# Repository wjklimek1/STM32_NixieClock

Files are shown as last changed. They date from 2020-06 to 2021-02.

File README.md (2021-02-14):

# STM32_NixieClock
Nixie clock based on STM32F103C8T6, DS3231 and MC34063

Nixie clock is driven by STM32F103C8T6 MCU reading data from DS3231 RTC clock. Step-up converter controlled by MC34063 produces 170V DC needed to power up display. Lamps are old japanese CD61 niexie tubes. 

Schematics and PCBs were designed with KiCad. In PDF folder you can find schematics from KiCad exported to PDF format for quick preview.

 Microcontroller program was written in C with HAL libraries and FreeRTOS. I know that any operating system is a total overkill when it comes to such a simple project but I used it to get familiar with FreeRTOS before I start more advanced projects.

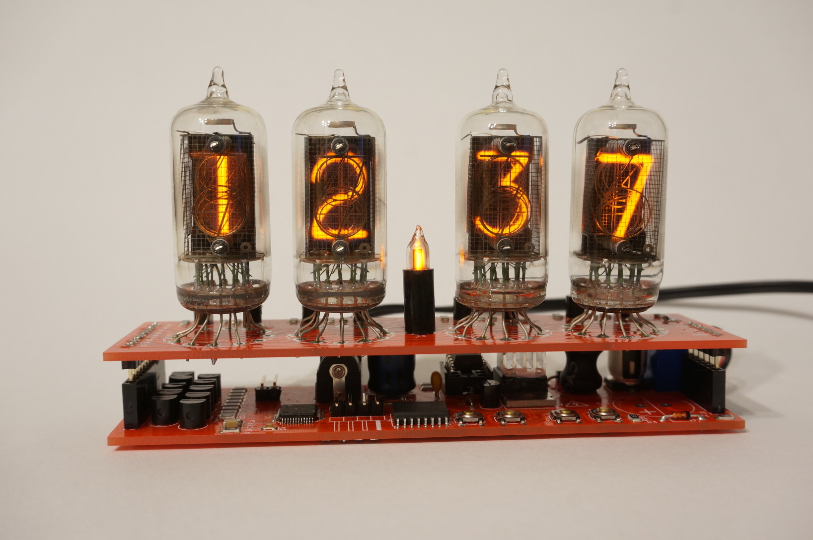
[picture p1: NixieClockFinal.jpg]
NixieClock


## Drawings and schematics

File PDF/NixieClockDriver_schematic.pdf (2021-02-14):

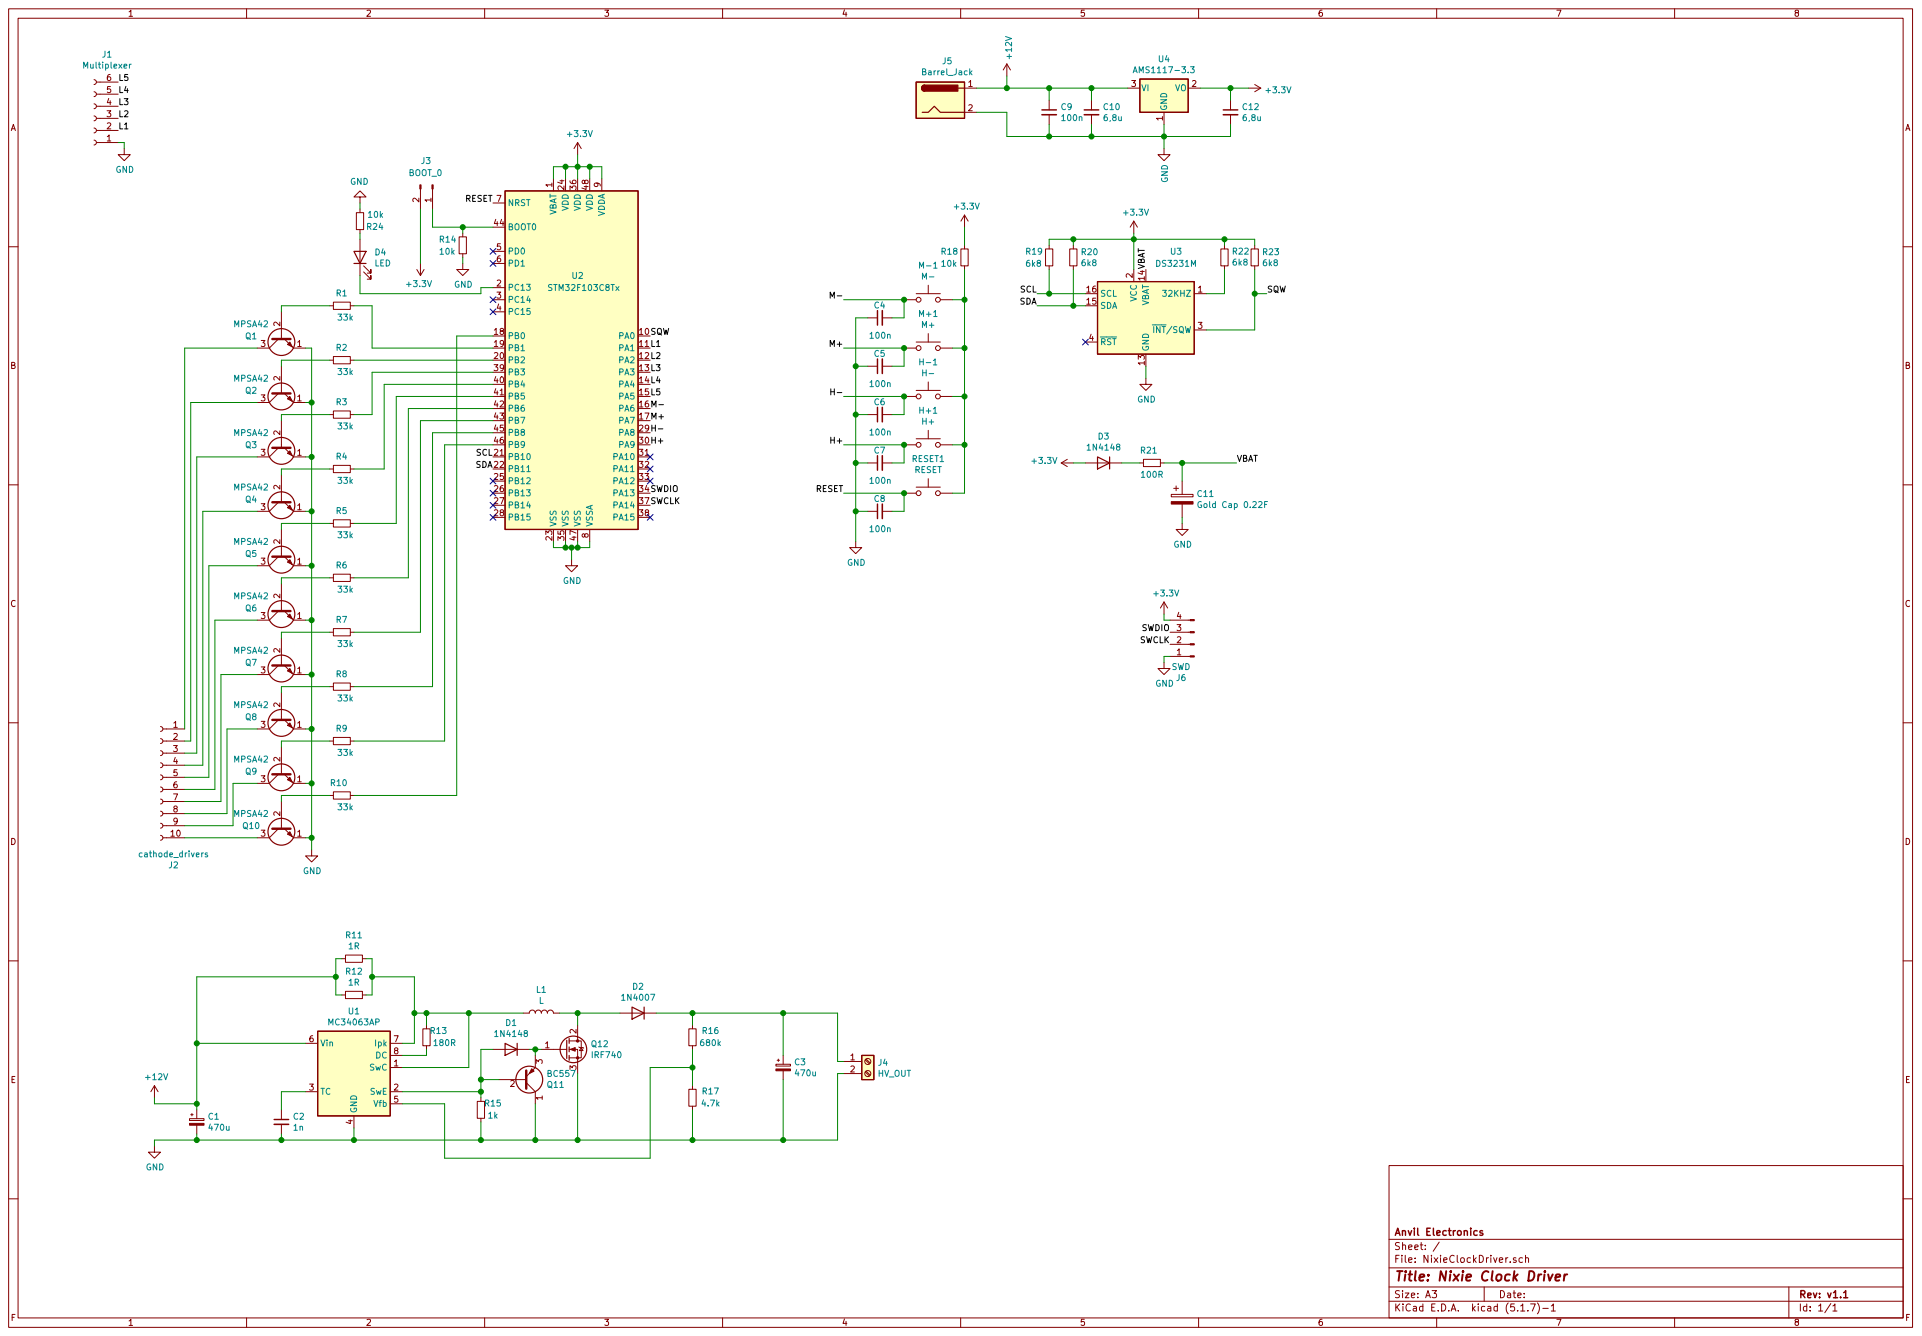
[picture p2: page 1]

Id: 1/1 Title: Nixie Clock Driver File: NixieClockDriver.sch Sheet: / Anvil Electronics

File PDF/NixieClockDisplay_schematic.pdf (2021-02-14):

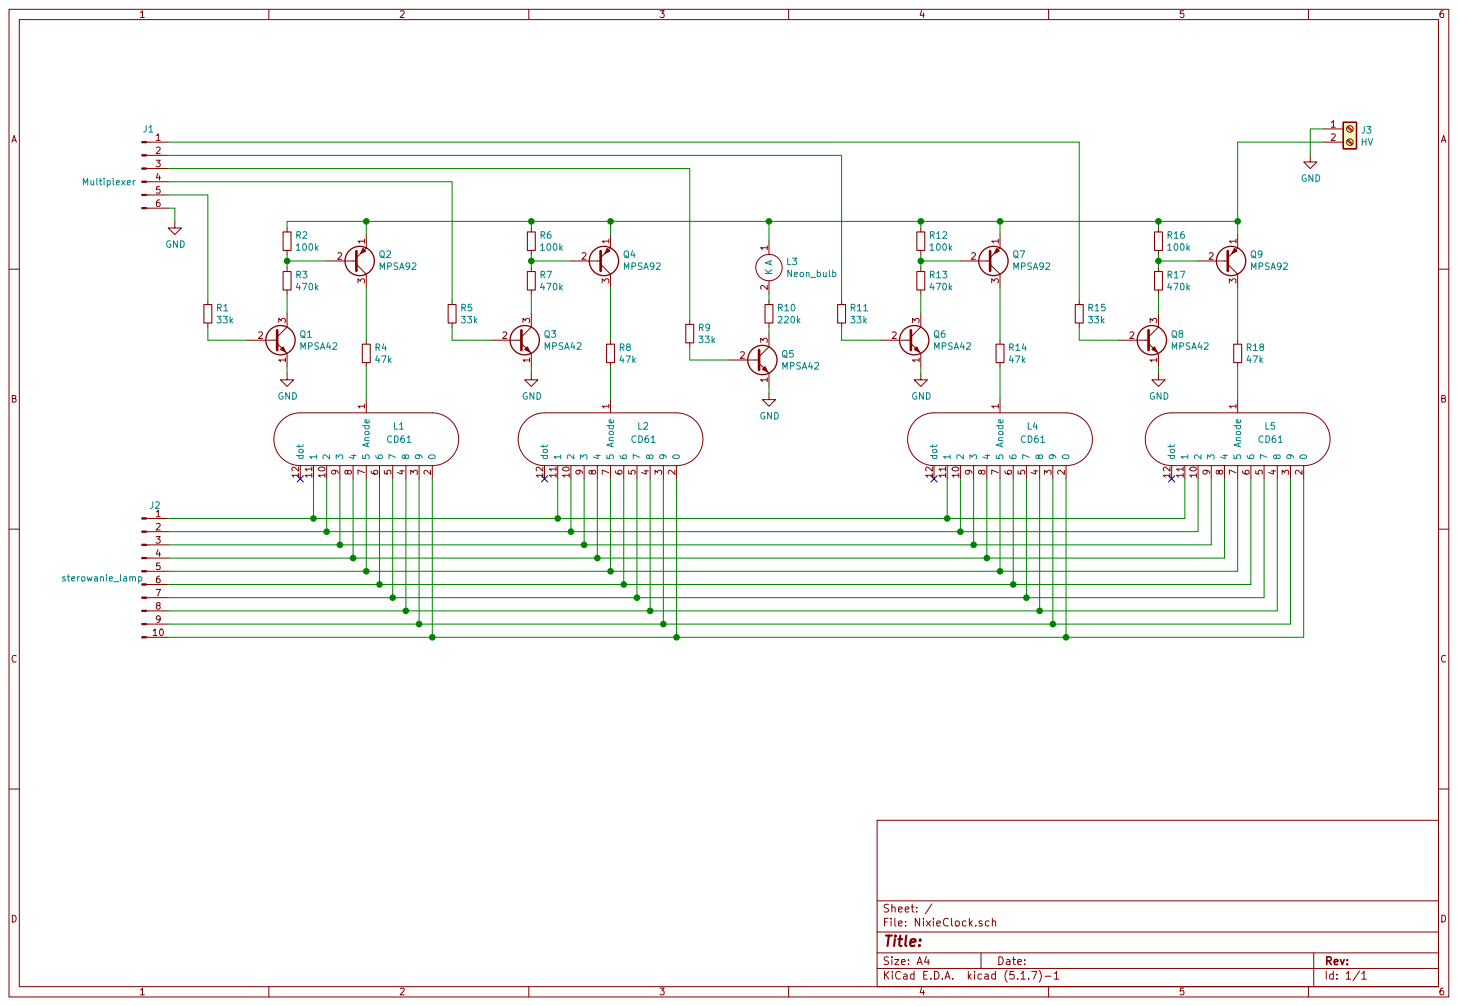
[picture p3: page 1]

Id: 1/1 Title: File: NixieClock.sch Sheet: /

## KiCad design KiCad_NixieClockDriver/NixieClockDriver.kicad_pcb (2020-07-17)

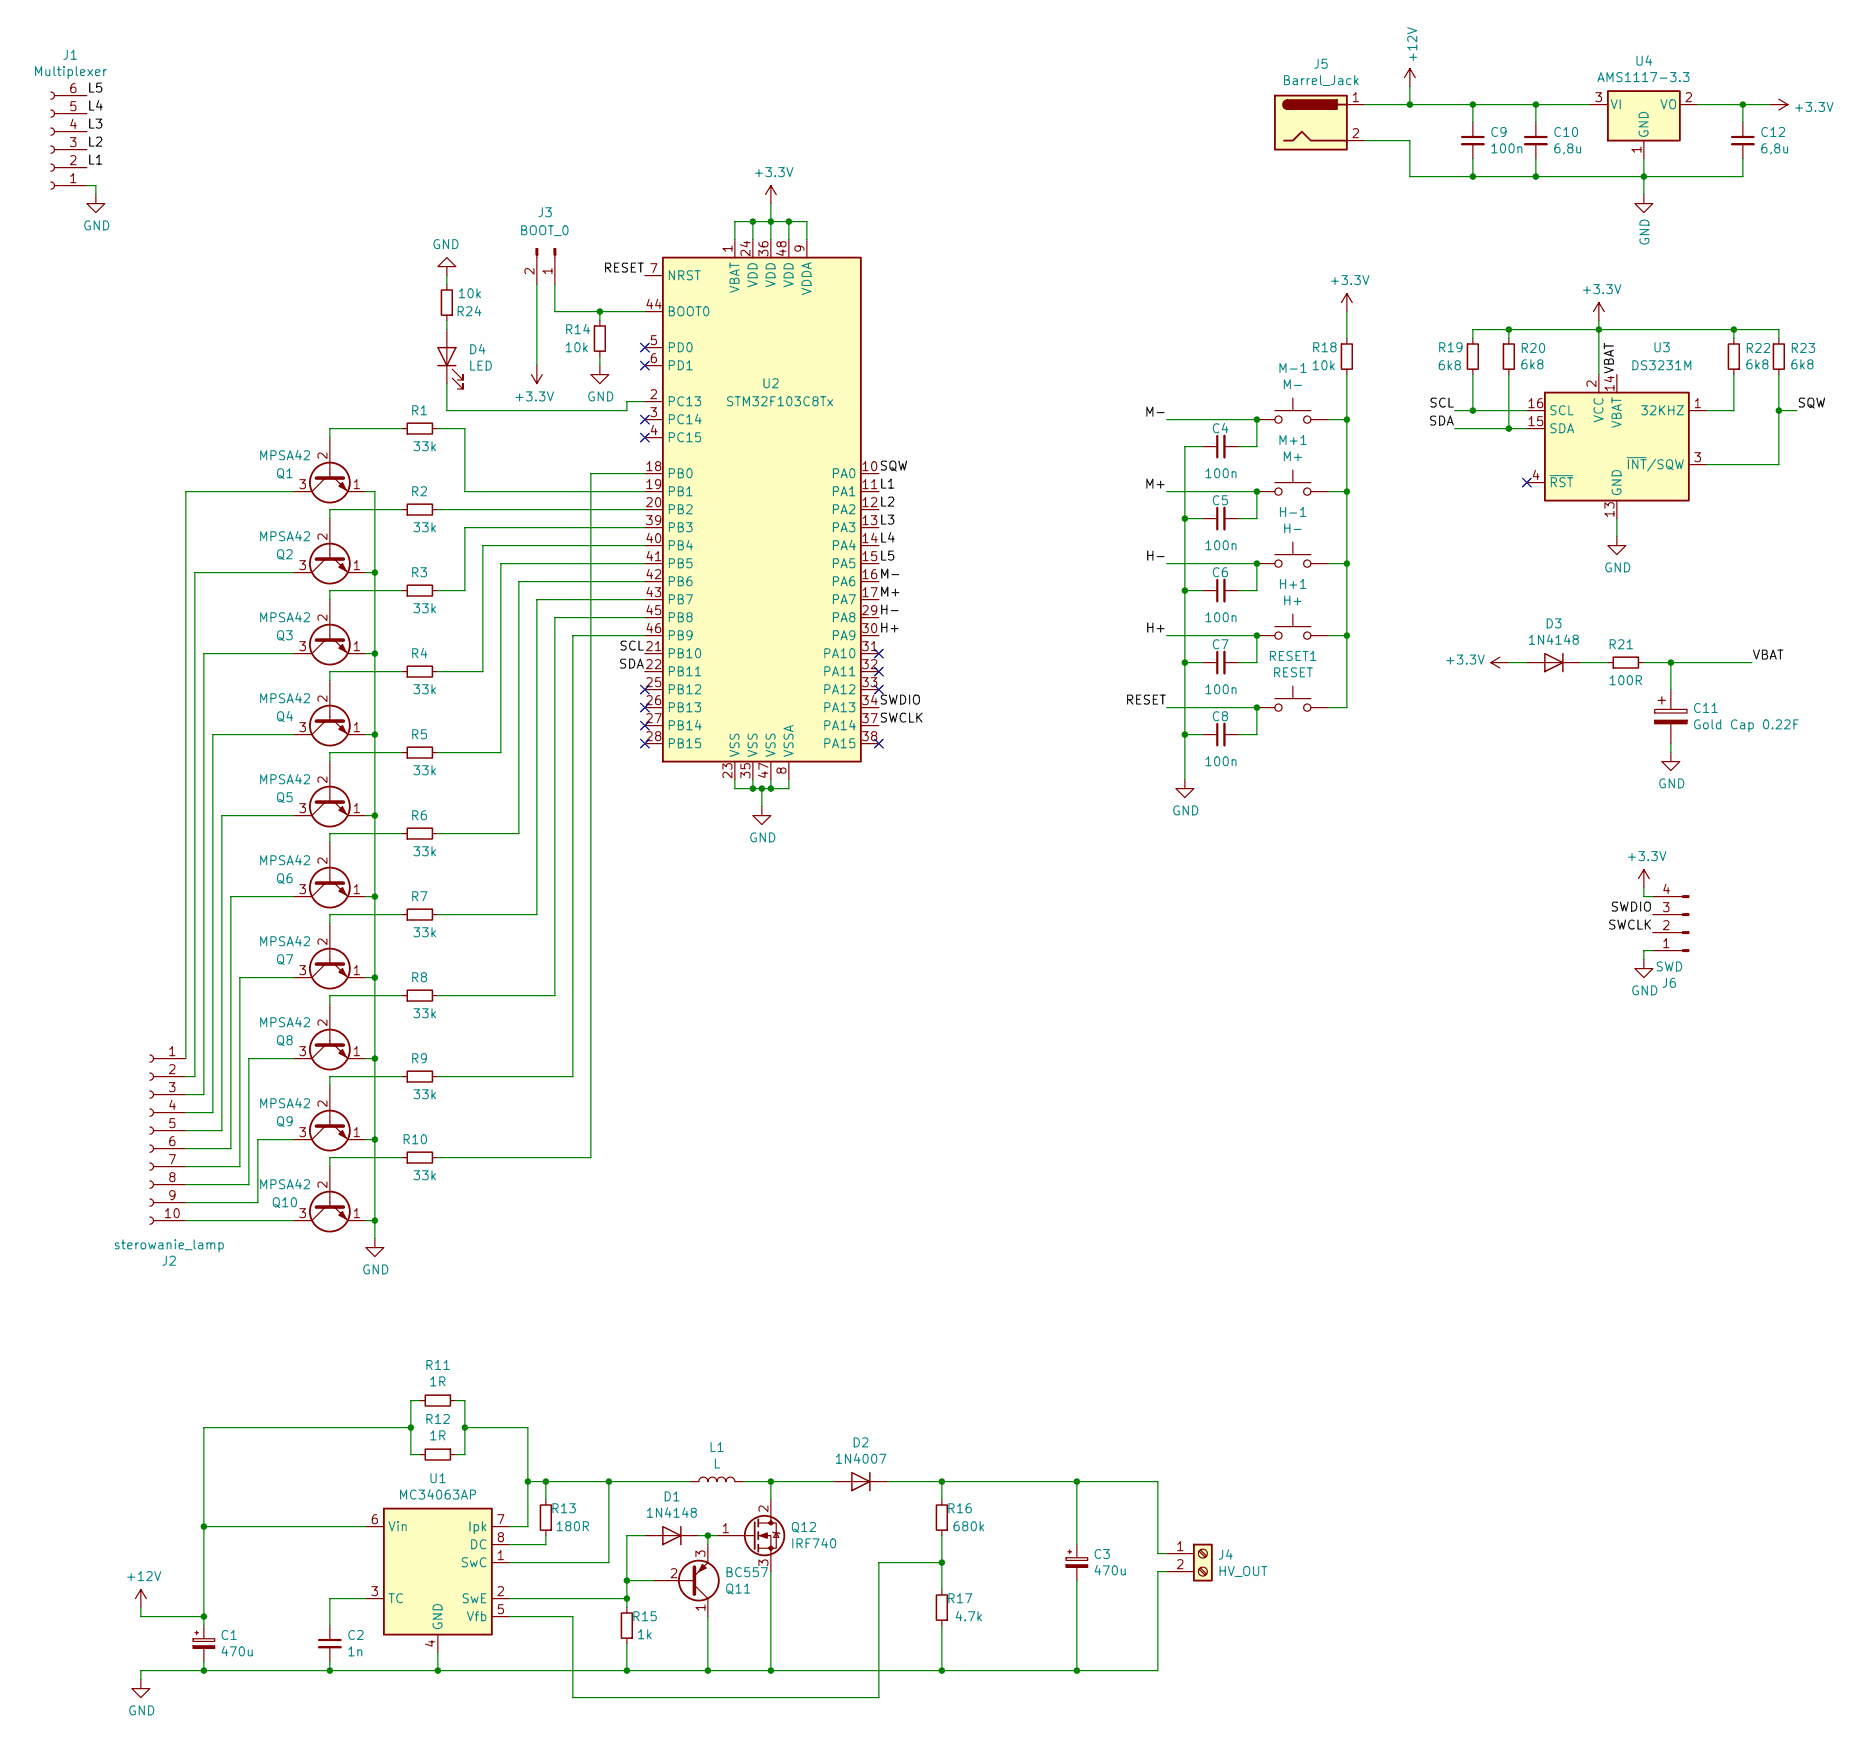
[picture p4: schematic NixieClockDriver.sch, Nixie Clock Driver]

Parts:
C1: 470u; CP_Radial_D10.0mm_P5.00mm
C2: 1n; C_Rect_L7.0mm_W2.0mm_P5.00mm
C3: 470u; CP_Elec_8x10.5
C4, C5, C6, C7, C8, C9: 100n; C_1206_3216Metric
C10, C12: 6,8u; C_1206_3216Metric
C11: Gold Cap 0.22F; GOLD_CAP
D1, D3: 1N4148; D_DO-35_SOD27_P7.62mm_Horizontal
D2: 1N4007; D_DO-41_SOD81_P10.16mm_Horizontal
D4: LED; LED_0805_2012Metric
H+1: H+; SW_SPST_TL3342
H-1: H-; SW_SPST_TL3342
J1: Multiplexer; PinSocket_1x06_P2.54mm_Vertical
J2: sterowanie_lamp; PinSocket_1x10_P2.54mm_Vertical
J3: BOOT_0; PinHeader_1x02_P2.54mm_Horizontal
J4: HV_OUT; TerminalBlock_bornier-2_P5.08mm
J5: Barrel_Jack; BarrelJack_Wuerth_6941xx301002
J6: SWD; PinHeader_1x04_P2.54mm_Horizontal
L1: L; L_Radial_D10.0mm_P5.00mm_Fastron_07P
M+1: M+; SW_SPST_TL3342
M-1: M-; SW_SPST_TL3342
Q1, Q2, Q3, Q4, Q5, Q6, Q7, Q8, Q9, Q10: MPSA42; TO-92_Inline
Q11: BC557; TO-92_Inline
Q12: IRF740; TO-220-3_Horizontal_TabDown
R1, R2, R3, R4, R5, R6, R7, R8, R9, R10: 33k; R_1206_3216Metric
R11, R12: 1R; R_1206_3216Metric
R13: 180R; R_1206_3216Metric
R14, R18, R24: 10k; R_1206_3216Metric
R15: 1k; R_1206_3216Metric
R16: 680k; R_1206_3216Metric
R17: 4.7k; R_1206_3216Metric
R19, R20, R22, R23: 6k8; R_1206_3216Metric
R21: 100R; R_1206_3216Metric
RESET1: RESET; SW_SPST_TL3342
U1: MC34063AP; DIP-8_W7.62mm
U2: STM32F103C8Tx; LQFP-48_7x7mm_P0.5mm
U3: DS3231M; SOIC-16W_7.5x10.3mm_P1.27mm
U4: AMS1117-3.3; SOT-223-3_TabPin2

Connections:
+3V3: C12.1, D3.2 (A), J3.2, J6.4, R18.1, R19.1, R20.1, R22.2, R23.1, U2.1 (VBAT), U2.9 (VDDA), U2.24 (VDD), U2.36 (VDD), U2.48 (VDD), U3.2 (VCC), U4.2 (VO)
+12V: C1.1, C9.1, C10.1, J5.1, R11.2, R12.2, U1.6 (Vin), U4.3 (VI)
/H+: C7.2, H+1.1, U2.30 (PA9)
/H-: C6.2, H-1.1, U2.29 (PA8)
/L1: J1.2, U2.11 (PA1)
/L2: J1.3, U2.12 (PA2)
/L3: J1.4, U2.13 (PA3)
/L4: J1.5, U2.14 (PA4)
/L5: J1.6, U2.15 (PA5)
/M+: C5.2, M+1.1, U2.17 (PA7)
/M-: C4.2, M-1.1, U2.16 (PA6)
/RESET: C8.2, RESET1.1, U2.7 (NRST)
/SCL: R19.2, U2.21 (PB10), U3.16 (SCL)
/SDA: R20.2, U2.22 (PB11), U3.15 (SDA)
/SQW: R23.2, U2.10 (PA0), U3.3 (~INT~/SQW)
/SWCLK: J6.2, U2.37 (PA14)
/SWDIO: J6.3, U2.34 (PA13)
/VBAT: C11.1, R21.2, U3.14 (VBAT)
GND: C1.2, C2.2, C3.2, C4.1, C5.1, C6.1, C7.1, C8.1, C9.2, C10.2, C11.2, C12.2, J1.1, J4.2, J5.2, J6.1, Q1.1 (E), Q2.1 (E), Q3.1 (E), Q4.1 (E), Q5.1 (E), Q6.1 (E), Q7.1 (E), Q8.1 (E), Q9.1 (E), Q10.1 (E), Q11.1 (C), Q12.3 (S), R14.2, R15.1, R17.1, R24.2, U1.4 (GND), U2.8 (VSSA), U2.23 (VSS), U2.35 (VSS), U2.47 (VSS), U3.5 (GND), U3.6 (GND), U3.7 (GND), U3.8 (GND), U3.9 (GND), U3.10 (GND), U3.11 (GND), U3.12 (GND), U3.13 (GND), U4.1 (GND)
unnamed: C2.1, U1.3 (TC)
unnamed: C3.1, D2.1 (K), J4.1, R16.2
unnamed: D1.1 (K), Q11.3 (E), Q12.1 (G)
unnamed: D1.2 (A), Q11.2 (B), R15.2, U1.2 (SwE)
unnamed: D2.2 (A), L1.2, Q12.2 (D)
unnamed: D3.1 (K), R21.1
unnamed: D4.1 (K), U2.2 (PC13)
unnamed: D4.2 (A), R24.1
unnamed: H+1.2, H-1.2, M+1.2, M-1.2, R18.2, RESET1.2
unnamed: J2.1, Q1.3 (C)
unnamed: J2.2, Q2.3 (C)
unnamed: J2.3, Q3.3 (C)
unnamed: J2.4, Q4.3 (C)
unnamed: J2.5, Q5.3 (C)
unnamed: J2.6, Q6.3 (C)
unnamed: J2.7, Q7.3 (C)
unnamed: J2.8, Q8.3 (C)
unnamed: J2.9, Q9.3 (C)
unnamed: J2.10, Q10.3 (C)
unnamed: J3.1, R14.1, U2.44 (BOOT0)
unnamed: L1.1, R11.1, R12.1, R13.2, U1.1 (SwC), U1.7 (Ipk)
unnamed: Q1.2 (B), R1.1
unnamed: Q2.2 (B), R2.1
unnamed: Q3.2 (B), R3.1
unnamed: Q4.2 (B), R4.1
unnamed: Q5.2 (B), R5.1
unnamed: Q6.2 (B), R6.1
unnamed: Q7.2 (B), R7.1
unnamed: Q8.2 (B), R8.1
unnamed: Q9.2 (B), R9.1
unnamed: Q10.2 (B), R10.1
unnamed: R1.2, U2.19 (PB1)
unnamed: R2.2, U2.20 (PB2)
unnamed: R3.2, U2.39 (PB3)
unnamed: R4.2, U2.40 (PB4)
unnamed: R5.2, U2.41 (PB5)
unnamed: R6.2, U2.42 (PB6)
unnamed: R7.2, U2.43 (PB7)
unnamed: R8.2, U2.45 (PB8)
unnamed: R9.2, U2.46 (PB9)
unnamed: R10.2, U2.18 (PB0)
unnamed: R13.1, U1.8 (DC)
unnamed: R16.1, R17.2, U1.5 (Vfb)
unnamed: R22.1, U3.1 (32KHZ)

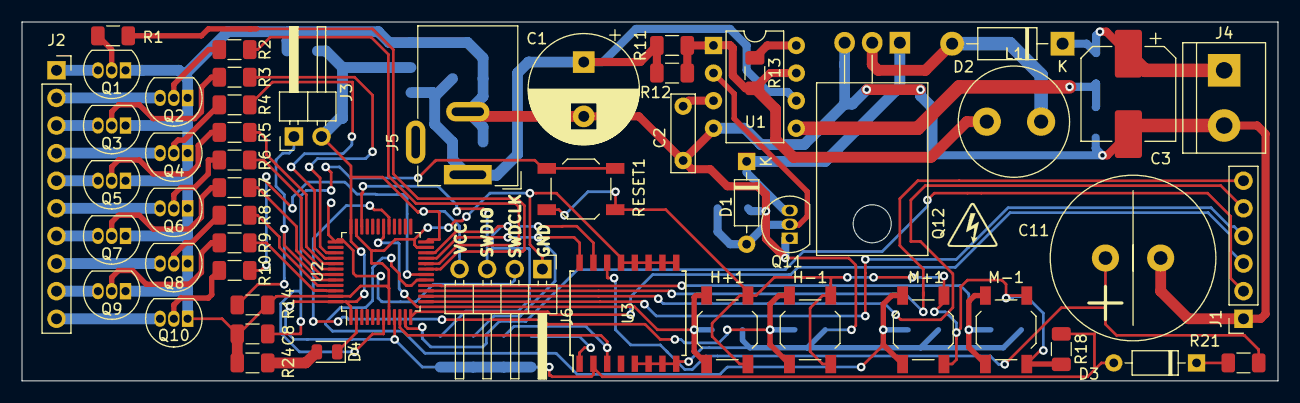
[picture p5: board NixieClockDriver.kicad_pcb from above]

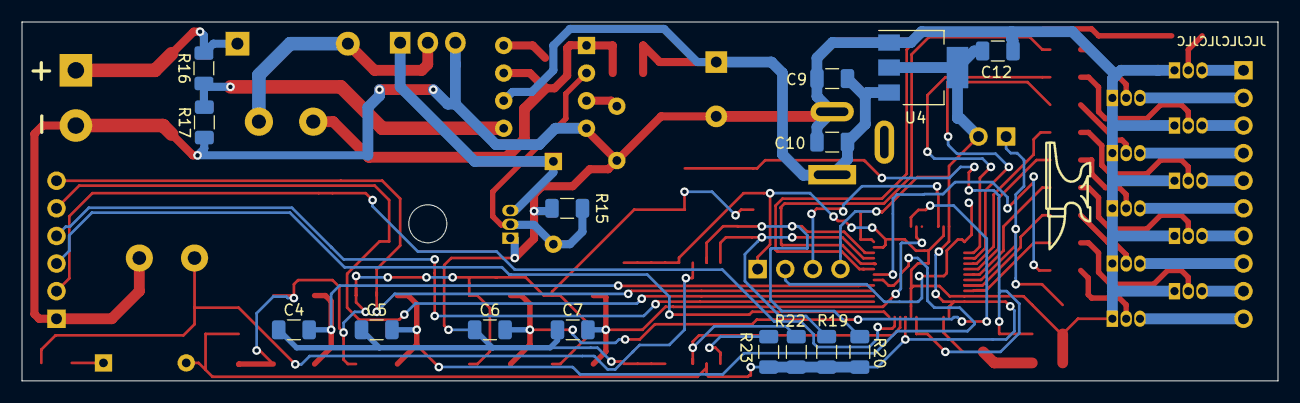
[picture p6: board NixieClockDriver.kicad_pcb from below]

Board: 2 copper layers, 115.6 x 33.0 mm, 68 parts (15 on the bottom side), 63 nets.

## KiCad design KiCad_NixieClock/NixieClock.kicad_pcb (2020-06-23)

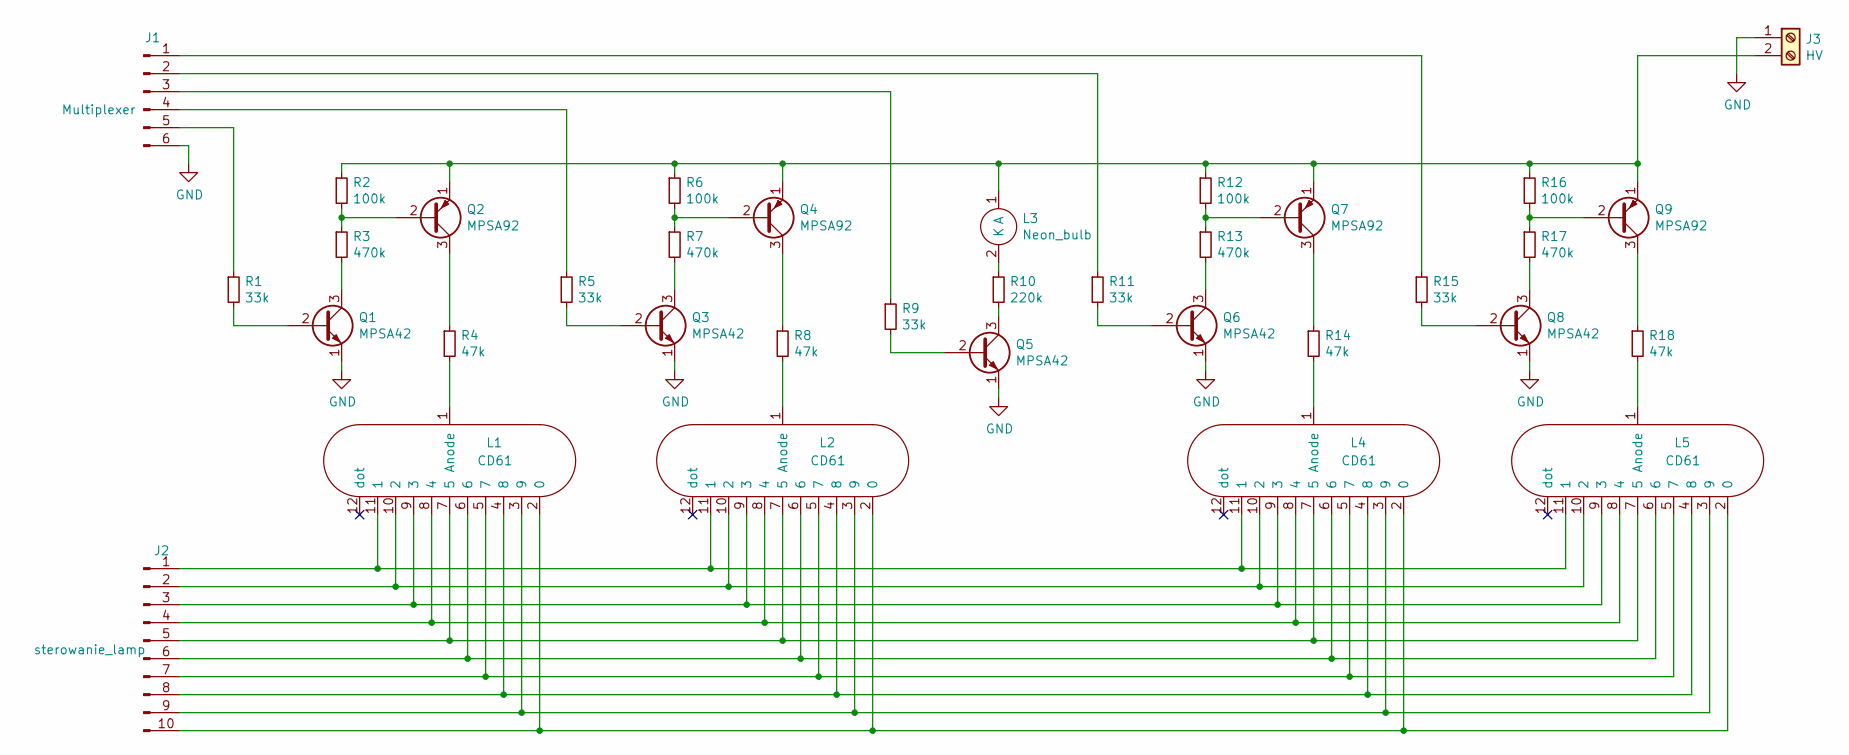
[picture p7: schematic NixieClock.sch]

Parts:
J1: Multiplexer; PinHeader_1x06_P2.54mm_Vertical
J2: sterowanie_lamp; PinHeader_1x10_P2.54mm_Vertical
J3: HV; TerminalBlock_bornier-2_P5.08mm
L1, L2, L4, L5: CD61; CD61_nixie
L3: Neon_bulb; neon_lamp
Q1, Q3, Q5, Q6, Q8: MPSA42; TO-92_Inline
Q2, Q4, Q7, Q9: MPSA92; TO-92_Inline
R1, R5, R9, R11, R15: 33k; R_1206_3216Metric_Pad1.42x1.75mm_HandSolder
R2, R6, R12, R16: 100k; R_1206_3216Metric_Pad1.42x1.75mm_HandSolder
R3, R7, R13, R17: 470k; R_1206_3216Metric_Pad1.42x1.75mm_HandSolder
R4, R8, R14, R18: 47k; R_1206_3216Metric_Pad1.42x1.75mm_HandSolder
R10: 220k; R_1206_3216Metric_Pad1.42x1.75mm_HandSolder

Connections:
GND: J1.6, J3.1, Q1.1 (E), Q3.1 (E), Q5.1 (E), Q6.1 (E), Q8.1 (E)
unnamed: J1.1, R15.1
unnamed: J1.2, R11.1
unnamed: J1.3, R9.1
unnamed: J1.4, R5.1
unnamed: J1.5, R1.1
unnamed: J2.1, L1.11 (1), L2.11 (1), L4.11 (1), L5.11 (1)
unnamed: J2.2, L1.10 (2), L2.10 (2), L4.10 (2), L5.10 (2)
unnamed: J2.3, L1.9 (3), L2.9 (3), L4.9 (3), L5.9 (3)
unnamed: J2.4, L1.8 (4), L2.8 (4), L4.8 (4), L5.8 (4)
unnamed: J2.5, L1.7 (5), L2.7 (5), L4.7 (5), L5.7 (5)
unnamed: J2.6, L1.6, L2.6, L4.6, L5.6
unnamed: J2.7, L1.5 (7), L2.5 (7), L4.5 (7), L5.5 (7)
unnamed: J2.8, L1.4 (8), L2.4 (8), L4.4 (8), L5.4 (8)
unnamed: J2.9, L1.3 (9), L2.3 (9), L4.3 (9), L5.3 (9)
unnamed: J2.10, L1.2 (0), L2.2 (0), L4.2 (0), L5.2 (0)
unnamed: J3.2, L3.1 (A), Q2.1 (E), Q4.1 (E), Q7.1 (E), Q9.1 (E), R2.1, R6.1, R12.1, R16.1
unnamed: L1.1 (Anode), R4.2
unnamed: L2.1 (Anode), R8.2
unnamed: L3.2 (K), R10.1
unnamed: L4.1 (Anode), R14.2
unnamed: L5.1 (Anode), R18.2
unnamed: Q1.2 (B), R1.2
unnamed: Q1.3 (C), R3.2
unnamed: Q2.2 (B), R2.2, R3.1
unnamed: Q2.3 (C), R4.1
unnamed: Q3.2 (B), R5.2
unnamed: Q3.3 (C), R7.2
unnamed: Q4.2 (B), R6.2, R7.1
unnamed: Q4.3 (C), R8.1
unnamed: Q5.2 (B), R9.2
unnamed: Q5.3 (C), R10.2
unnamed: Q6.2 (B), R11.2
unnamed: Q6.3 (C), R13.2
unnamed: Q7.2 (B), R12.2, R13.1
unnamed: Q7.3 (C), R14.1
unnamed: Q8.2 (B), R15.2
unnamed: Q8.3 (C), R17.2
unnamed: Q9.2 (B), R16.2, R17.1
unnamed: Q9.3 (C), R18.1

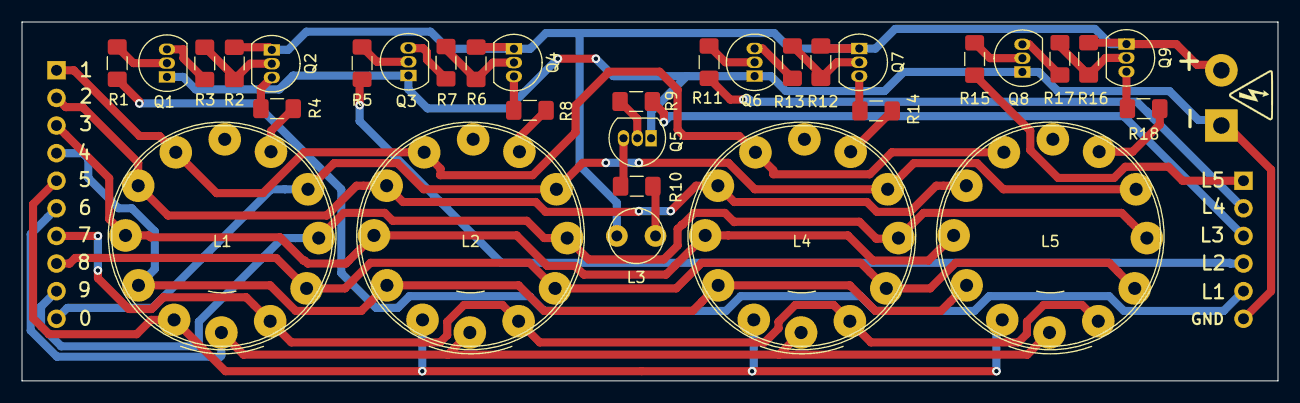
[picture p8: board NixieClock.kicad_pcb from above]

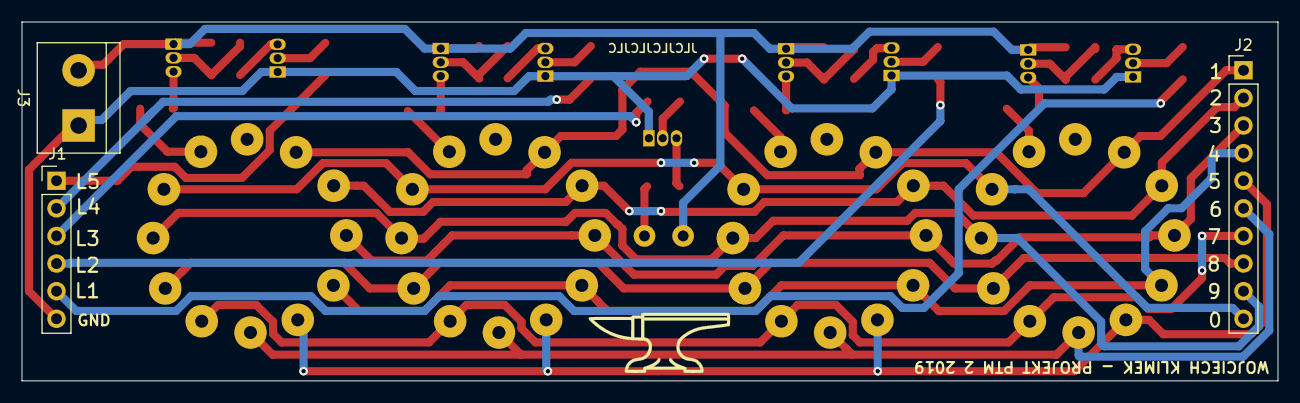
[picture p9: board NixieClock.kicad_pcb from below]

Board: 2 copper layers, 115.6 x 33.0 mm, 35 parts (3 on the bottom side), 40 nets.

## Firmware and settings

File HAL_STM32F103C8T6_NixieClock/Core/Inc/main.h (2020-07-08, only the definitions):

#define LED_Pin GPIO_PIN_13
#define LED_GPIO_Port GPIOC
#define SQW_Pin GPIO_PIN_0
#define SQW_GPIO_Port GPIOA
#define SQW_EXTI_IRQn EXTI0_IRQn
#define L1_Pin GPIO_PIN_1
#define L1_GPIO_Port GPIOA
#define L2_Pin GPIO_PIN_2
#define L2_GPIO_Port GPIOA
#define L3_Pin GPIO_PIN_3
#define L3_GPIO_Port GPIOA
#define L4_Pin GPIO_PIN_4
#define L4_GPIO_Port GPIOA
#define L5_Pin GPIO_PIN_5
#define L5_GPIO_Port GPIOA
#define M_MINUS_Pin GPIO_PIN_6
#define M_MINUS_GPIO_Port GPIOA
#define M_MINUS_EXTI_IRQn EXTI9_5_IRQn
#define M_PLUS_Pin GPIO_PIN_7
#define M_PLUS_GPIO_Port GPIOA
#define M_PLUS_EXTI_IRQn EXTI9_5_IRQn
#define N0_Pin GPIO_PIN_0
#define N0_GPIO_Port GPIOB
#define N1_Pin GPIO_PIN_1
#define N1_GPIO_Port GPIOB
#define N2_Pin GPIO_PIN_2
#define N2_GPIO_Port GPIOB
#define H_MINUS_Pin GPIO_PIN_8
#define H_MINUS_GPIO_Port GPIOA
#define H_MINUS_EXTI_IRQn EXTI9_5_IRQn
#define H_PLUS_Pin GPIO_PIN_9
#define H_PLUS_GPIO_Port GPIOA
#define H_PLUS_EXTI_IRQn EXTI9_5_IRQn
#define N3_Pin GPIO_PIN_3
#define N3_GPIO_Port GPIOB
#define N4_Pin GPIO_PIN_4
#define N4_GPIO_Port GPIOB
#define N5_Pin GPIO_PIN_5
#define N5_GPIO_Port GPIOB
#define N6_Pin GPIO_PIN_6
#define N6_GPIO_Port GPIOB
#define N7_Pin GPIO_PIN_7
#define N7_GPIO_Port GPIOB
#define N8_Pin GPIO_PIN_8
#define N8_GPIO_Port GPIOB
#define N9_Pin GPIO_PIN_9
#define N9_GPIO_Port GPIOB

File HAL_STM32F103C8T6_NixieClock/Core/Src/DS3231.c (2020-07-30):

/*
 * stm32_ds3231.c
 *
 *  Created on: 2019. 3. 17.
 *      Author: kiki
 */
#include "stm32f1xx_hal.h"
#include "DS3231.h"

#define DS3231_ADDR  (0x68 << 1)

I2C_HandleTypeDef *i2c;

static uint8_t B2D(uint8_t bcd);
static uint8_t D2B(uint8_t decimal);

void DS3231_Init(I2C_HandleTypeDef *handle)
{
  i2c = handle;
}

bool DS3231_GetTime(_RTC *rtc)
{
  uint8_t startAddr = DS3231_REG_TIME;
  uint8_t buffer[7] = {0,};

  if(HAL_I2C_Master_Transmit(i2c, DS3231_ADDR, &startAddr, 1, HAL_MAX_DELAY) != HAL_OK) return false;
  if(HAL_I2C_Master_Receive(i2c, DS3231_ADDR, buffer, sizeof(buffer), HAL_MAX_DELAY) != HAL_OK) return false;

  rtc->Sec = B2D(buffer[0] & 0x7F);
  rtc->Min = B2D(buffer[1] & 0x7F);
  rtc->Hour = B2D(buffer[2] & 0x3F);
  rtc->DaysOfWeek = buffer[3] & 0x07;
  rtc->Date = B2D(buffer[4] & 0x3F);
  rtc->Month = B2D(buffer[5] & 0x1F);
  rtc->Year = B2D(buffer[6]);

  return true;
}

bool DS3231_SetTime(_RTC *rtc)
{
  uint8_t startAddr = DS3231_REG_TIME;
  uint8_t buffer[8] = {startAddr, D2B(rtc->Sec), D2B(rtc->Min), D2B(rtc->Hour), rtc->DaysOfWeek, D2B(rtc->Date), D2B(rtc->Month), D2B(rtc->Year)};
  if(HAL_I2C_Master_Transmit(i2c, DS3231_ADDR, buffer, sizeof(buffer), HAL_MAX_DELAY) != HAL_OK) return false;

  return true;
}

bool DS3231_ReadTemperature(float *temp)
{
  ForceConversion();

  uint8_t startAddr = DS3231_REG_TEMP;
  uint8_t buffer[2] = {0,};

  if(HAL_I2C_Master_Transmit(i2c, DS3231_ADDR, &startAddr, 1, HAL_MAX_DELAY) != HAL_OK) return false;
  if(HAL_I2C_Master_Receive(i2c, DS3231_ADDR, buffer, sizeof(buffer), HAL_MAX_DELAY) != HAL_OK) return false;

  int16_t value = (buffer[0] << 8) | (buffer[1]);
  value = (value >> 6);

  *temp = value / 4.0f;
  return true;
}

bool DS3231_SetAlarm1(uint8_t mode, uint8_t date, uint8_t hour, uint8_t min, uint8_t sec)
{
  uint8_t alarmSecond = D2B(sec);
  uint8_t alarmMinute = D2B(min);
  uint8_t alarmHour = D2B(hour);
  uint8_t alarmDate = D2B(date);

  switch(mode)
  {
  case ALARM_MODE_ALL_MATCHED:
    break;
  case ALARM_MODE_HOUR_MIN_SEC_MATCHED:
    alarmDate |= 0x80;
    break;
  case ALARM_MODE_MIN_SEC_MATCHED:
    alarmDate |= 0x80;
    alarmHour |= 0x80;
    break;
  case ALARM_MODE_SEC_MATCHED:
    alarmDate |= 0x80;
    alarmHour |= 0x80;
    alarmMinute |= 0x80;
    break;
  case ALARM_MODE_ONCE_PER_SECOND:
    alarmDate |= 0x80;
    alarmHour |= 0x80;
    alarmMinute |= 0x80;
    alarmSecond |= 0x80;
    break;
  default:
    break;
  }

  /* Write Alarm Registers */
  uint8_t startAddr = DS3231_REG_ALARM1;
  uint8_t buffer[5] = {startAddr, alarmSecond, alarmMinute, alarmHour, alarmDate};
  if(HAL_I2C_Master_Transmit(i2c, DS3231_ADDR, buffer, sizeof(buffer), HAL_MAX_DELAY) != HAL_OK) return false;

  /* Enable Alarm1 at Control Register */
  uint8_t ctrlReg = 0x00;
  ReadRegister(DS3231_REG_CONTROL, &ctrlReg);
  ctrlReg |= DS3231_CON_A1IE;
  ctrlReg |= DS3231_CON_INTCN;
  WriteRegister(DS3231_REG_CONTROL, ctrlReg);

  return true;
}

bool DS3231_ClearAlarm1()
{
  uint8_t ctrlReg;
  uint8_t statusReg;

  /* Clear Control Register */
  ReadRegister(DS3231_REG_CONTROL, &ctrlReg);
  ctrlReg &= ~DS3231_CON_A1IE;
  WriteRegister(DS3231_REG_CONTROL, ctrlReg);

  /* Clear Status Register */
  ReadRegister(DS3231_REG_STATUS, &statusReg);
  statusReg &= ~DS3231_STA_A1F;
  WriteRegister(DS3231_REG_STATUS, statusReg);

  return true;
}

bool ReadRegister(uint8_t regAddr, uint8_t *value)
{
  if(HAL_I2C_Master_Transmit(i2c, DS3231_ADDR, &regAddr, 1, HAL_MAX_DELAY) != HAL_OK) return false;
  if(HAL_I2C_Master_Receive(i2c, DS3231_ADDR, value, 1, HAL_MAX_DELAY) != HAL_OK) return false;

  return true;
}

bool WriteRegister(uint8_t regAddr, uint8_t value)
{
  uint8_t buffer[2] = {regAddr, value};
  if(HAL_I2C_Master_Transmit(i2c, DS3231_ADDR, buffer, sizeof(buffer), HAL_MAX_DELAY) != HAL_OK) return false;

  return true;
}

static uint8_t B2D(uint8_t bcd)
{
  return (bcd >> 4) * 10 + (bcd & 0x0F);
}

static uint8_t D2B(uint8_t decimal)
{
  return (((decimal / 10) << 4) | (decimal % 10));
}

bool ForceConversion()
{
	uint8_t value;

	ReadRegister(DS3231_REG_CONTROL, &value);

	value |= 0b00100000;

	WriteRegister(DS3231_REG_CONTROL, value);

	while ((value & 0b00100000) != 0)
	{
		ReadRegister(DS3231_REG_CONTROL, &value);
	}
}

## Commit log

2020-06-23 KiCad projects for top and bottom PCB
    + KiCad project for top and bottom PCB's added
    [NixieClock.kicad_pcb, NixieClock.sch, NixieClockDriver.kicad_pcb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]
2020-07-08 CubeIDE project with FreeRTOS
    + peripherials initialization in CubeIDE
    + buttons handling with interrups and semaphores
    + shared memory and I2C mutexes added
2020-07-09 Readings from RTC
    + Added simple library for DS3231 RTC
    + Changing RTC time with buttons
    + Middle neon lamp now blinks with 1Hz frequency
2020-07-10 Final software version
    + Improved buttons handling
    + Added nixie tubes multiplexer
2020-07-17 Fixed reversed transistor in driver schematic
    [NixieClockDriver.kicad_pcb, NixieClockDriver.sch]
2020-07-30 Display temperature after startup
    + added "ForceConversion" function to DS3231 library. This function has to be called before "ReadTemperature" to force ADC conversion in RTC
    + display DS3231 temperature for a few seconds after startup. Useful to check temperature inside case.
2021-02-14 Schematics in PDF
    + added schematics in PDF format for quick preview without KiCad
    + small changes in component description placemnt for better readability
    [NixieClockDriver.sch]

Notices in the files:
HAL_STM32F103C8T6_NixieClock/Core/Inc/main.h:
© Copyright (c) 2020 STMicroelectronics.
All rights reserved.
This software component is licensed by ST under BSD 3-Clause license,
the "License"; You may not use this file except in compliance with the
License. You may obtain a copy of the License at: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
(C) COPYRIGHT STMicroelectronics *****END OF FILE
